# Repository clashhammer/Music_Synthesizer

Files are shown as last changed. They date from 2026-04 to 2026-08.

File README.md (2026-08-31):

# Music_Synthesizer
A project that studies the effect of sound and how waves produce it. Works like a piano and has a screen that outputs like a digital oscilloscope showing the wave that you hear and telling you it's frequency.

I got the idea from a girl I know that wants to be a singer and she said she wanted to buy a synthesizer to get a step closer to composing her own song. That's when I thought "how cool it would be to try and make one, maybe even give it to her if it turns out good.". And yeah, that's basically how I got an idea to build a musical synthesizer.

## Bill of Materials

| Part | Quantity | Price | Link |
|---|---:|---:|---|
| ESP32 DevKit V1 | 1 | €6.89 | [Buy](https://share.temu.com/K3tj6sE6siB) |
| PCM5102 DAC Module | 2 | €2.65 | [Buy](https://a.aliexpress.com/_ExivHVu) |
| XH-A156 Amplifier Board | 1 | €1.29 | [Buy](https://a.aliexpress.com/_EQBbn1Y) |
| 2W 8Ω Speaker | 4 | €2.16 | [Buy](https://a.aliexpress.com/_EGUYYXC) |
| SN74HC595N Shift Register | 1 | €1.93 | [Buy](https://a.aliexpress.com/_EvkP7yO) |
| GMT020-02-8P TFT Display | 1 | — | Any compatible ST7789 TFT display should work |
| Push Button | 26 | — | Any suitable push button set should work |
| 1N4148 Diode | 24 | €3.86 | [Buy](https://share.temu.com/MGWPABEpR8B) |
| 10kΩ Resistor | 4 | €0.87 | [Buy](https://share.temu.com/5ZgNjFWWyZB) |
| 100nF Ceramic Capacitor | 1 | — | Any 100 nF ceramic capacitor should work |

To build a prototype follow the schematic and see where each wire is connected then upload the code to the ESP32 to use it. My own prototype uses just one custom PAM 8403 amplifier board and just one PCM5102 DAC board. I have color coded and connected all parts adjusting to the pinout and code in the schematic for easy understanding.

Also for the code you'll need to download some libraries from the ARDUINO IDE library picker for the code to propperly compile. These are:
- ESP_I2S (should be the second one in the list)
- Adafruit_GFX (again should be second one)
- Adafruit_ST7789 (first one this time)

I also have some custom part signs that I've uploaded as a rar file.

Btw if you haven't used ESP32 before (like me), to connect it to your computer and upload the code you need to install a driver, corelating to what your ESP32 type is. There is a little chip under the big one on the board. To install the correct drivers you need to see what the letters on this chip say. If they say "SILABS CP210x" you need to install the CP210x driver. If it says "CH340" you need to install the CH340 driver on your computer. if it says nothing you need to install the CH340 driver.

Here are the links to both drivers' sites
- CP210x - https://www.silabs.com/software-and-tools/usb-to-uart-bridge-vcp-drivers?tab=overview

- CH340 - https://www.wch-ic.com/downloads/CH341SER_EXE.html

Here are some photos of the finished part of the project like schematic, pcb and 3D display of it and youtube video of how it works.





Youtube video (unlisted): https://youtube.com/shorts/R9iYHdPvPAw

This isn't final and I'll make more updates in the future, thus the not so explanatory explanations.

I added an MIT Licence for free use of my project files.

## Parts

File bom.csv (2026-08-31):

Part | Quantity | Price | Link
ESP32 DevKit V1 | 1 | €6 | 89 | https://share.temu.com/K3tj6sE6siB
PCM5102 DAC Module | 2 | €2 | 65 | https://a.aliexpress.com/_ExivHVu
XH-A156 Amplifier Board | 1 | €1.29 | https://a.aliexpress.com/_EQBbn1Y
2W 8Ω Speaker | 4 | €2.16 | https://a.aliexpress.com/_EGUYYXC
SN74HC595N Shift Register | 1 | €1.93 | https://a.aliexpress.com/_EvkP7yO
GMT020-02-8P TFT Display | 1 |  | can't find a link | any ST7789 TFT display should work.
Push Button | 26 |  | can't find link | any push button set should work
1N4148 Diode | 24 | €3 | 86 | https://share.temu.com/MGWPABEpR8B
10k Ohm Resistor | 4 | €0 | 87 | https://share.temu.com/5ZgNjFWMyZB
100nF Ceramic Capacitor | 1 |  | can't find a direct link | any 100 nF ceramic capacitor should work.

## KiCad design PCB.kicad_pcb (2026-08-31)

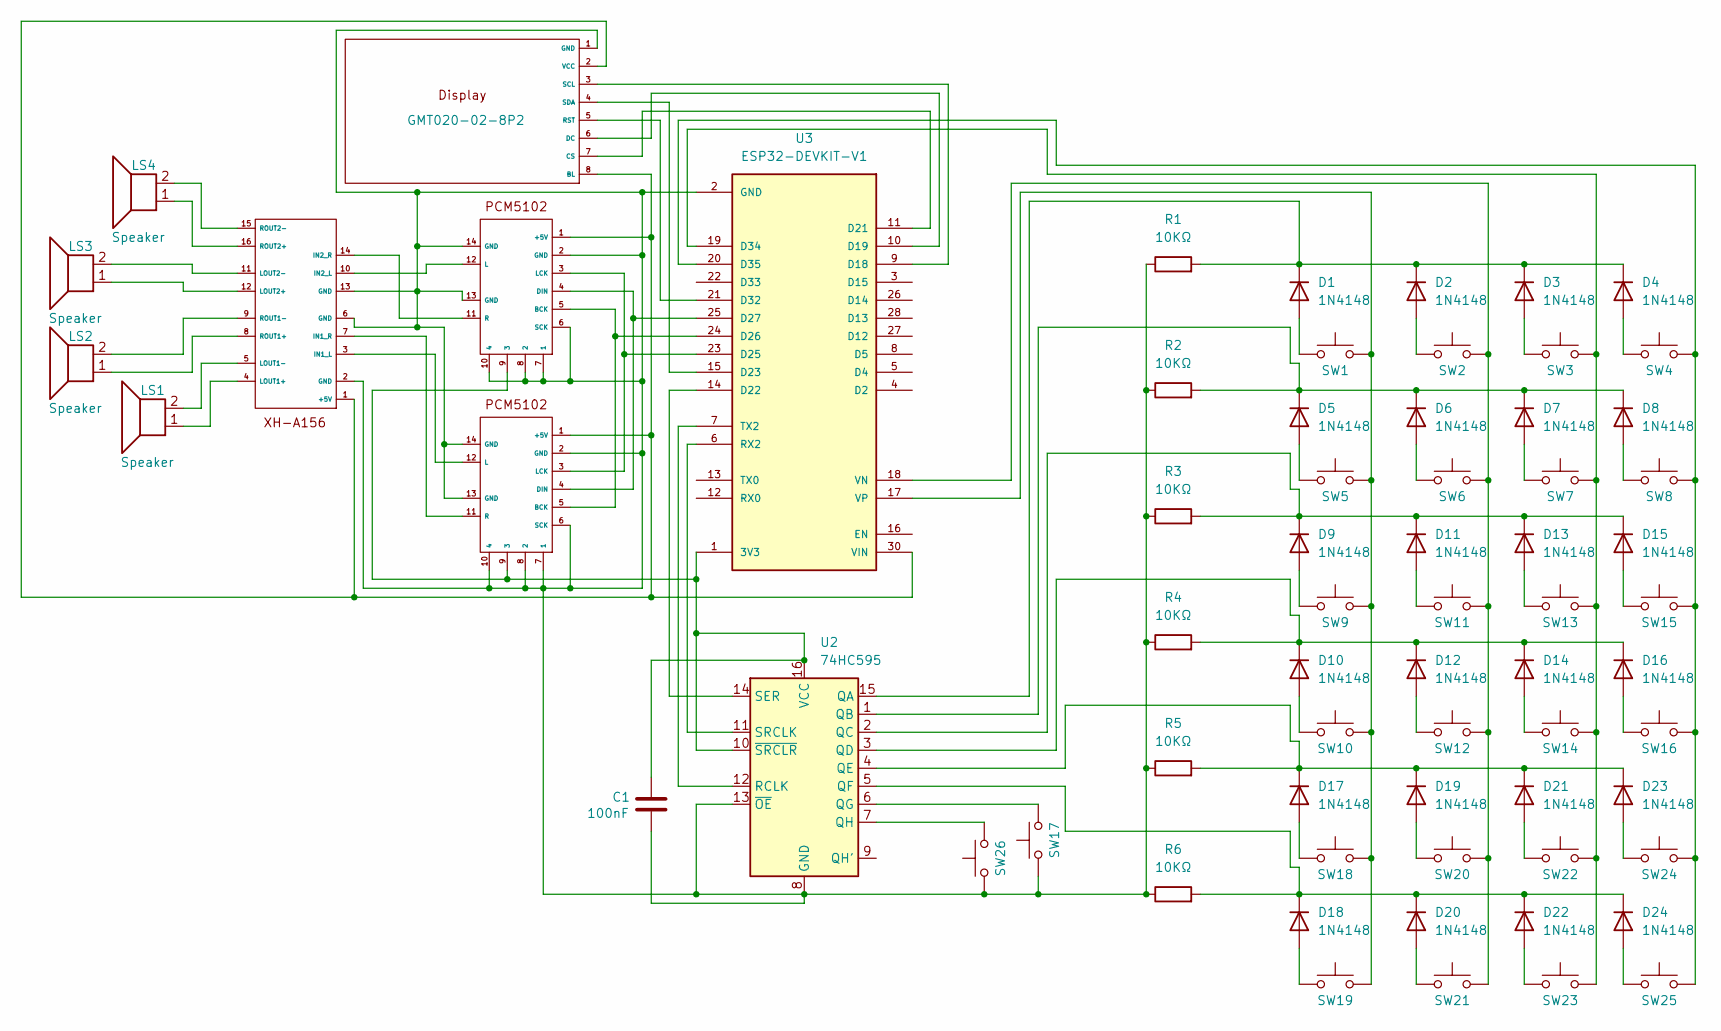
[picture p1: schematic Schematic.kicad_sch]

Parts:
C1: 100nF; C_Disc_D5.0mm_W2.5mm_P5.00mm
D1, D2, D3, D4, D5, D6, D7, D8, D9, D10, D11, D12, D13, D14, D15, D16, D17, D18, D19, D20, D21, D22, D23, D24: 1N4148; D_DO-35_SOD27_P7.62mm_Horizontal
GMT020-02-8P2: GMT020-02-8P
LS1, LS2, LS3, LS4: Speaker; PinHeader_1x02_P2.54mm_Horizontal
PCM1, PCM3: PCM5102
R1, R2, R3, R4, R5, R6: 10KΩ; R_Axial_DIN0207_L6.3mm_D2.5mm_P7.62mm_Horizontal
SW1, SW2, SW3, SW4, SW5, SW6, SW7, SW8, SW9, SW10, SW11, SW12, SW13, SW14, SW15, SW16, SW18, SW19, SW20, SW21, SW22, SW23, SW24, SW25: SW_Push; SW_PUSH-12mm
SW17, SW26: SW_Push; SW_PUSH_6mm
U2: 74HC595; DIP-16_W7.62mm
U3: ESP32-DEVKIT-V1; MODULE_ESP32_DEVKIT_V1; PARTREV N/A
XH-A1: XH-A156 4-way amplifier board

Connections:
GND: C1.2, GMT020-02-8P2.1 (GND), PCM1.2 (GND), PCM1.6 (SCK), PCM1.7 (1), PCM1.8 (2), PCM1.10 (4), PCM1.13 (GND), PCM1.14 (GND), PCM3.2 (GND), PCM3.6 (SCK), PCM3.7 (1), PCM3.8 (2), PCM3.10 (4), PCM3.13 (GND), PCM3.14 (GND), R1.1, R2.1, R3.1, R4.1, R5.1, R6.1, SW17.1, SW26.1, U2.8 (GND), U2.13 (~OE), U3.2 (GND), U3.29 (GND), XH-A1.2 (GND), XH-A1.6 (GND), XH-A1.13 (GND)
unnamed: D1.2 (A), SW1.1
unnamed: D1.1 (K), D2.1 (K), D3.1 (K), D4.1 (K), R1.2, U2.15 (QA)
unnamed: D2.2 (A), SW2.1
unnamed: D3.2 (A), SW3.1
unnamed: D4.2 (A), SW4.1
unnamed: D5.2 (A), SW5.1
unnamed: D5.1 (K), D6.1 (K), D7.1 (K), D8.1 (K), R2.2, U2.1 (QB)
unnamed: D6.2 (A), SW6.1
unnamed: D7.2 (A), SW7.1
unnamed: D8.2 (A), SW8.1
unnamed: D9.2 (A), SW9.1
unnamed: D10.2 (A), SW10.1
unnamed: D10.1 (K), D12.1 (K), D14.1 (K), D16.1 (K), R4.2, U2.3 (QD)
unnamed: D11.2 (A), SW11.1
unnamed: D9.1 (K), D11.1 (K), D13.1 (K), D15.1 (K), R3.2, U2.2 (QC)
unnamed: D12.2 (A), SW12.1
unnamed: D13.2 (A), SW13.1
unnamed: D14.2 (A), SW14.1
unnamed: D15.2 (A), SW15.1
unnamed: D16.2 (A), SW16.1
unnamed: D17.2 (A), SW18.1
unnamed: D17.1 (K), D19.1 (K), D21.1 (K), D23.1 (K), R5.2, U2.4 (QE)
unnamed: D18.2 (A), SW19.1
unnamed: D18.1 (K), D20.1 (K), D22.1 (K), D24.1 (K), R6.2, U2.5 (QF)
unnamed: D19.2 (A), SW20.1
unnamed: D20.2 (A), SW21.1
unnamed: D21.2 (A), SW22.1
unnamed: D22.2 (A), SW23.1
unnamed: D23.2 (A), SW24.1
unnamed: D24.2 (A), SW25.1
unnamed: GMT020-02-8P2.2 (VCC), GMT020-02-8P2.8 (BL), PCM1.1 (+5V), PCM3.1 (+5V), U3.30 (VIN), XH-A1.1 (+5V)
unnamed: GMT020-02-8P2.7 (CS), U3.11 (D21)
unnamed: GMT020-02-8P2.6 (DC), U3.10 (D19)
unnamed: GMT020-02-8P2.5 (RST), U3.21 (D32)
unnamed: GMT020-02-8P2.3 (SCL), U3.9 (D18)
unnamed: GMT020-02-8P2.4 (SDA), U3.15 (D23)
unnamed: C1.1, PCM1.9 (3), PCM3.9 (3), U2.10 (~SRCLR), U2.16 (VCC), U3.1 (3V3)
unnamed: PCM1.5 (BCK), PCM3.5 (BCK), U3.24 (D26)
unnamed: PCM1.4 (DIN), PCM3.4 (DIN), U3.25 (D27)
unnamed: PCM1.12 (L), XH-A1.10 (IN2_L)
unnamed: PCM1.3 (LCK), PCM3.3 (LCK), U3.23 (D25)
unnamed: PCM1.11 (R), XH-A1.14 (IN2_R)
unnamed: PCM3.12 (L), XH-A1.3 (IN1_L)
unnamed: PCM3.11 (R), XH-A1.7 (IN1_R)
unnamed: SW17.2, U2.6 (QG)
unnamed: SW26.2, U2.7 (QH)
unnamed: U2.12 (RCLK), U3.7 (TX2)
unnamed: U2.14 (SER), U3.14 (D22)
unnamed: U2.11 (SRCLK), U3.6 (RX2)
unnamed: SW3.2, SW7.2, SW13.2, SW14.2, SW22.2, SW23.2, U3.19 (D34)
unnamed: SW4.2, SW8.2, SW15.2, SW16.2, SW24.2, SW25.2, U3.20 (D35)
unnamed: SW2.2, SW6.2, SW11.2, SW12.2, SW20.2, SW21.2, U3.18 (VN)
unnamed: SW1.2, SW5.2, SW9.2, SW10.2, SW18.2, SW19.2, U3.17 (VP)
unnamed: LS1.1, XH-A1.4 (LOUT1+)
unnamed: LS1.2, XH-A1.5 (LOUT1-)
unnamed: LS3.1, XH-A1.12 (LOUT2+)
unnamed: LS3.2, XH-A1.11 (LOUT2-)
unnamed: LS2.1, XH-A1.8 (ROUT1+)
unnamed: LS2.2, XH-A1.9 (ROUT1-)
unnamed: LS4.1, XH-A1.16 (ROUT2+)
unnamed: LS4.2, XH-A1.15 (ROUT2-)

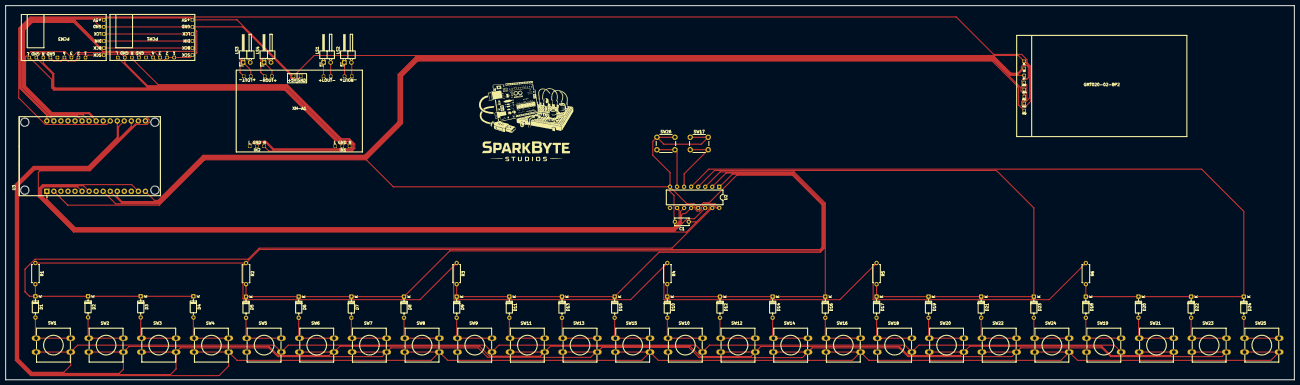
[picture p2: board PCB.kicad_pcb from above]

Board: 2 copper layers, 465.0 x 135.0 mm, 67 parts (0 on the bottom side), 62 nets.

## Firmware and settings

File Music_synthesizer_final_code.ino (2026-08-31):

#include <Arduino.h>
#include <ESP_I2S.h>
#include <SPI.h>
#include <Adafruit_GFX.h>
#include <Adafruit_ST7789.h>

constexpr uint8_t I2S_LCK = 25;
constexpr uint8_t I2S_DIN = 27;
constexpr uint8_t I2S_BCK = 26;

constexpr uint8_t SHIFT_DATA = 22;
constexpr uint8_t SHIFT_CLOCK = 16;
constexpr uint8_t SHIFT_LATCH = 17;

constexpr uint8_t TFT_SCK = 18;
constexpr uint8_t TFT_MOSI = 23;
constexpr uint8_t TFT_CS = 21;
constexpr uint8_t TFT_DC = 19;
constexpr uint8_t TFT_RST = 32;

constexpr uint8_t MATRIX_ROWS = 6;
constexpr uint8_t MATRIX_COLS = 4;
constexpr uint8_t NUM_KEYS = 24;

constexpr uint8_t COL_PINS[MATRIX_COLS] = {
  36,
  39,
  34,
  35
};

constexpr uint8_t WAVE_OUTPUT = 6;
constexpr uint8_t TONE_OUTPUT = 7;

constexpr uint8_t WAVE_COUNT = 5;
constexpr uint8_t TONE_COUNT = 5;

constexpr uint32_t SAMPLE_RATE = 44100;
constexpr uint16_t AUDIO_FRAMES = 128;
constexpr uint16_t SCOPE_BUFFER_SIZE = 4096;

constexpr float TWO_PI_F = 6.28318530718f;
constexpr float MASTER_VOLUME = 0.05f;

const float notes[NUM_KEYS] = {
  261.63f,
  277.18f,
  293.66f,
  311.13f,
  329.63f,
  349.23f,
  369.99f,
  392.00f,
  415.30f,
  440.00f,
  466.16f,
  493.88f,
  523.25f,
  554.37f,
  587.33f,
  622.25f,
  659.25f,
  698.46f,
  739.99f,
  783.99f,
  830.61f,
  880.00f,
  932.33f,
  987.77f
};

const char* noteNames[NUM_KEYS] = {
  "C4",
  "C#4",
  "D4",
  "D#4",
  "E4",
  "F4",
  "F#4",
  "G4",
  "G#4",
  "A4",
  "A#4",
  "B4",
  "C5",
  "C#5",
  "D5",
  "D#5",
  "E5",
  "F5",
  "F#5",
  "G5",
  "G#5",
  "A5",
  "A#5",
  "B5"
};

const char* waveNames[WAVE_COUNT] = {
  "SINE",
  "SQUARE",
  "SAW",
  "TRIANGLE",
  "PULSE"
};

const char* toneNames[TONE_COUNT] = {
  "NORMAL",
  "BASS",
  "TREBLE",
  "MELLOW",
  "BRIGHT"
};

I2SClass I2S;

Adafruit_ST7789 tft(TFT_CS, TFT_DC, TFT_RST);

volatile uint32_t pressedMask = 0;
volatile uint8_t waveType = 0;
volatile uint8_t toneType = 0;

uint32_t debounceMask = 0;
uint32_t previousMask = 0;
uint32_t debounceStart = 0;

bool waveRaw = false;
bool waveStable = false;
uint32_t waveChangeTime = 0;

bool toneRaw = false;
bool toneStable = false;
uint32_t toneChangeTime = 0;

uint32_t lastDisplayUpdate = 0;

float phases[NUM_KEYS] = {};
float gains[NUM_KEYS] = {};

float bassLP = 0.0f;
float trebleLP = 0.0f;
float mellowLP = 0.0f;
float brightLP = 0.0f;

int16_t audioBuffer[AUDIO_FRAMES * 2];

volatile int16_t scopeBuffer[SCOPE_BUFFER_SIZE] = {};
volatile uint16_t scopeWriteIndex = 0;

constexpr int16_t SCREEN_W = 320;
constexpr int16_t SCREEN_H = 240;

constexpr int16_t SCOPE_X = 45;
constexpr int16_t SCOPE_Y = 31;
constexpr int16_t SCOPE_W = 270;
constexpr int16_t SCOPE_H = 155;

void write595(uint8_t value) {
  digitalWrite(SHIFT_LATCH, LOW);
  shiftOut(SHIFT_DATA, SHIFT_CLOCK, MSBFIRST, value);
  digitalWrite(SHIFT_LATCH, HIGH);
}

uint32_t scanMatrix() {
  uint32_t result = 0;

  for (uint8_t row = 0; row < MATRIX_ROWS; row++) {
    write595(1 << row);

    delayMicroseconds(10);

    for (uint8_t column = 0; column < MATRIX_COLS; column++) {
      if (digitalRead(COL_PINS[column]) == HIGH) {
        uint8_t key = row * MATRIX_COLS + column;
        result |= (1UL << key);
      }
    }
  }

  write595(0x00);

  return result;
}

void updateKeyboard() {
  uint32_t rawMask = scanMatrix();
  uint32_t now = millis();

  if (rawMask != debounceMask) {
    debounceMask = rawMask;
    debounceStart = now;
  }

  if (now - debounceStart >= 8) {
    pressedMask = debounceMask;
  }
}

bool readShiftButton(uint8_t output) {
  write595(1 << output);

  delayMicroseconds(10);

  bool pressed =
    digitalRead(COL_PINS[0]) == HIGH;

  write595(0x00);

  return pressed;
}

void updateControlButtons() {
  uint32_t now = millis();

  bool newWaveRaw =
    readShiftButton(WAVE_OUTPUT);

  if (newWaveRaw != waveRaw) {
    waveRaw = newWaveRaw;
    waveChangeTime = now;
  }

  if (
    now - waveChangeTime >= 25 &&
    waveStable != waveRaw
  ) {
    waveStable = waveRaw;

    if (waveStable) {
      waveType++;

      if (waveType >= WAVE_COUNT) {
        waveType = 0;
      }

      Serial.print("WAVE: ");
      Serial.println(waveNames[waveType]);
    }
  }

  bool newToneRaw =
    readShiftButton(TONE_OUTPUT);

  if (newToneRaw != toneRaw) {
    toneRaw = newToneRaw;
    toneChangeTime = now;
  }

  if (
    now - toneChangeTime >= 25 &&
    toneStable != toneRaw
  ) {
    toneStable = toneRaw;

    if (toneStable) {
      toneType++;

      if (toneType >= TONE_COUNT) {
        toneType = 0;
      }

      Serial.print("TONE: ");
      Serial.println(toneNames[toneType]);
    }
  }
}

float generateWave(uint8_t type, float phase) {
  switch (type) {
    case 0:
      return sinf(phase);

    case 1:
      return phase < PI
        ? 1.0f
        : -1.0f;

    case 2:
      return phase / PI - 1.0f;

    case 3:
      if (phase < PI) {
        return -1.0f +
          2.0f * phase / PI;
      }

      return 3.0f -
        2.0f * phase / PI;

    case 4:
      return phase <
        TWO_PI_F * 0.20f
        ? 1.0f
        : -1.0f;
  }

  return 0.0f;
}

float processTone(
  float sample,
  uint8_t type
) {
  switch (type) {
    case 0:
      return sample;

    case 1:
      bassLP +=
        0.035f *
        (sample - bassLP);

      return
        sample * 0.60f +
        bassLP * 0.70f;

    case 2: {
      trebleLP +=
        0.25f *
        (sample - trebleLP);

      float high =
        sample - trebleLP;

      return
        sample * 0.70f +
        high * 0.75f;
    }

    case 3:
      mellowLP +=
        0.15f *
        (sample - mellowLP);

      return mellowLP;

    case 4: {
      brightLP +=
        0.15f *
        (sample - brightLP);

      float high =
        sample - brightLP;

      return
        sample * 0.75f +
        high * 0.50f;
    }
  }

  return sample;
}

void generateAudio() {
  const float attackStep =
    1.0f /
    (0.008f * SAMPLE_RATE);

  const float releaseStep =
    1.0f /
    (0.030f * SAMPLE_RATE);

  uint32_t currentKeys =
    pressedMask;

  uint8_t currentWave =
    waveType;

  uint8_t currentTone =
    toneType;

  uint32_t newlyPressed =
    currentKeys &
    ~previousMask;

  for (
    uint8_t key = 0;
    key < NUM_KEYS;
    key++
  ) {
    if (
      newlyPressed &
      (1UL << key)
    ) {
      phases[key] = 0.0f;
    }
  }

  previousMask =
    currentKeys;

  for (
    uint16_t frame = 0;
    frame < AUDIO_FRAMES;
    frame++
  ) {
    float mix = 0.0f;
    uint8_t voices = 0;

    for (
      uint8_t key = 0;
      key < NUM_KEYS;
      key++
    ) {
      bool pressed =
        currentKeys &
        (1UL << key);

      if (pressed) {
        gains[key] +=
          attackStep;

        if (
          gains[key] >
          1.0f
        ) {
          gains[key] =
            1.0f;
        }
      } else {
        gains[key] -=
          releaseStep;

        if (
          gains[key] <
          0.0f
        ) {
          gains[key] =
            0.0f;
        }
      }

      if (
        gains[key] >
        0.0001f
      ) {
        float wave =
          generateWave(
            currentWave,
            phases[key]
          );

        mix +=
          wave *
          gains[key];

        voices++;

        phases[key] +=
          TWO_PI_F *
          notes[key] /
          SAMPLE_RATE;

        if (
          phases[key] >=
          TWO_PI_F
        ) {
          phases[key] -=
            TWO_PI_F;
        }
      }
    }

    if (voices > 1) {
      mix /= voices;
    }

    mix =
      processTone(
        mix,
        currentTone
      );

    mix =
      constrain(
        mix,
        -1.0f,
        1.0f
      );

    int16_t scopeSample =
      static_cast<int16_t>(
        mix *
        32767.0f
      );

    scopeBuffer[
      scopeWriteIndex
    ] =
      scopeSample;

    scopeWriteIndex++;

    if (
      scopeWriteIndex >=
      SCOPE_BUFFER_SIZE
    ) {
      scopeWriteIndex = 0;
    }

    int16_t sample =
      static_cast<int16_t>(
        mix *
        MASTER_VOLUME *
        32767.0f
      );

    audioBuffer[
      frame * 2
    ] =
      sample;

    audioBuffer[
      frame * 2 + 1
    ] =
      sample;
  }

  I2S.write(
    reinterpret_cast<uint8_t*>(
      audioBuffer
    ),
    sizeof(audioBuffer)
  );
}

void audioTask(
  void* parameter
) {
  while (true) {
    generateAudio();
  }
}

uint8_t countVoices(
  uint32_t mask
) {
  uint8_t voices = 0;

  for (
    uint8_t key = 0;
    key < NUM_KEYS;
    key++
  ) {
    if (
      mask &
      (1UL << key)
    ) {
      voices++;
    }
  }

  return voices;
}

float lowestFrequency(
  uint32_t mask
) {
  for (
    uint8_t key = 0;
    key < NUM_KEYS;
    key++
  ) {
    if (
      mask &
      (1UL << key)
    ) {
      return notes[key];
    }
  }

  return 0.0f;
}

void drawStaticScreen() {
  tft.fillScreen(
    ST77XX_BLACK
  );

  tft.setTextWrap(false);

  tft.drawRect(
    SCOPE_X,
    SCOPE_Y,
    SCOPE_W,
    SCOPE_H,
    ST77XX_WHITE
  );

  tft.setTextColor(
    ST77XX_WHITE
  );

  tft.setTextSize(1);

  tft.setCursor(
    3,
    SCOPE_Y - 3
  );

  tft.print("+1");

  tft.setCursor(
    12,
    SCOPE_Y +
    SCOPE_H / 2 -
    3
  );

  tft.print("0");

  tft.setCursor(
    3,
    SCOPE_Y +
    SCOPE_H -
    6
  );

  tft.print("-1");
}

uint16_t findTriggeredStart(
  uint16_t endIndex,
  uint16_t sampleSpan
) {
  int32_t start =
    static_cast<int32_t>(
      endIndex
    ) -
    sampleSpan -
    200;

  while (start < 0) {
    start +=
      SCOPE_BUFFER_SIZE;
  }

  uint16_t candidate =
    static_cast<uint16_t>(
      start
    );

  for (
    uint16_t i = 1;
    i < 200;
    i++
  ) {
    uint16_t previousIndex =
      (candidate + i - 1) %
      SCOPE_BUFFER_SIZE;

    uint16_t currentIndex =
      (candidate + i) %
      SCOPE_BUFFER_SIZE;

    int16_t previous =
      scopeBuffer[
        previousIndex
      ];

    int16_t current =
      scopeBuffer[
        currentIndex
      ];

    if (
      previous < 0 &&
      current >= 0
    ) {
      return currentIndex;
    }
  }

  return candidate;
}

void drawHeader(
  uint32_t keys,
  uint8_t currentWave,
  uint8_t currentTone
) {
  tft.fillRect(
    0,
    0,
    SCREEN_W,
    29,
    ST77XX_BLACK
  );

  tft.setTextSize(1);

  uint8_t voices =
    countVoices(keys);

  if (voices == 0) {
    tft.setTextColor(
      ST77XX_YELLOW
    );

    tft.setCursor(4, 5);
    tft.print("NO NOTE");
  }

  if (voices == 1) {
    for (
      uint8_t key = 0;
      key < NUM_KEYS;
      key++
    ) {
      if (
        keys &
        (1UL << key)
      ) {
        tft.setTextColor(
          ST77XX_YELLOW
        );

        tft.setCursor(
          4,
          5
        );

        tft.print(
          noteNames[key]
        );

        tft.print(" ");

        tft.print(
          notes[key],
          2
        );

        tft.print("Hz");

        break;
      }
    }
  }

  if (voices > 1) {
    tft.setTextColor(
      ST77XX_YELLOW
    );

    tft.setCursor(4, 5);

    tft.print(voices);
    tft.print(" NOTES");
  }

  tft.setTextColor(
    ST77XX_CYAN
  );

  tft.setCursor(
    245,
    4
  );

  tft.print(
    waveNames[
      currentWave
    ]
  );

  tft.setTextColor(
    ST77XX_MAGENTA
  );

  tft.setCursor(
    245,
    16
  );

  tft.print(
    toneNames[
      currentTone
    ]
  );
}

void drawFrequencyList(
  uint32_t keys
) {
  tft.fillRect(
    0,
    190,
    SCREEN_W,
    50,
    ST77XX_BLACK
  );

  tft.setTextSize(1);

  tft.setTextColor(
    ST77XX_WHITE
  );

  uint8_t active = 0;

  for (
    uint8_t key = 0;
    key < NUM_KEYS;
    key++
  ) {
    if (
      keys &
      (1UL << key)
    ) {
      if (active < 8) {
        uint8_t column =
          active % 4;

        uint8_t row =
          active / 4;

        int16_t x =
          3 +
          column * 79;

        int16_t y =
          194 +
          row * 14;

        tft.setCursor(
          x,
          y
        );

        tft.print(
          notes[key],
          1
        );
      }

      active++;
    }
  }

  if (active == 0) {
    tft.setCursor(
      3,
      194
    );

    tft.print(
      "Frequency: --"
    );
  }

  if (active > 8) {
    tft.setCursor(
      3,
      222
    );

    tft.print("+");
    tft.print(active - 8);
    tft.print(" more");
  }
}

void drawScope(
  uint32_t keys
) {
  tft.fillRect(
    SCOPE_X + 1,
    SCOPE_Y + 1,
    SCOPE_W - 2,
    SCOPE_H - 2,
    ST77XX_BLACK
  );

  uint16_t grid =
    tft.color565(
      40,
      40,
      40
    );

  for (
    uint8_t i = 1;
    i < 4;
    i++
  ) {
    int16_t x =
      SCOPE_X +
      (SCOPE_W * i) /
      4;

    tft.drawFastVLine(
      x,
      SCOPE_Y + 1,
      SCOPE_H - 2,
      grid
    );
  }

  for (
    uint8_t i = 1;
    i < 4;
    i++
  ) {
    int16_t y =
      SCOPE_Y +
      (SCOPE_H * i) /
      4;

    tft.drawFastHLine(
      SCOPE_X + 1,
      y,
      SCOPE_W - 2,
      grid
    );
  }

  int16_t centerY =
    SCOPE_Y +
    SCOPE_H / 2;

  tft.drawFastHLine(
    SCOPE_X + 1,
    centerY,
    SCOPE_W - 2,
    tft.color565(
      90,
      90,
      90
    )
  );

  float frequency =
    lowestFrequency(keys);

  uint16_t sampleSpan =
    700;

  if (
    frequency >
    0.0f
  ) {
    sampleSpan =
      static_cast<uint16_t>(
        SAMPLE_RATE *
        3.0f /
        frequency
      );

    if (
      sampleSpan <
      100
    ) {
      sampleSpan =
        100;
    }

    if (
      sampleSpan >
      1800
    ) {
      sampleSpan =
        1800;
    }
  }

  uint16_t endIndex =
    scopeWriteIndex;

  uint16_t startIndex =
    findTriggeredStart(
      endIndex,
      sampleSpan
    );

  int16_t previousX =
    SCOPE_X + 1;

  int16_t firstSample =
    scopeBuffer[
      startIndex
    ];

  int16_t previousY =
    centerY -
    static_cast<int32_t>(
      firstSample
    ) *
    (SCOPE_H / 2 - 6) /
    32768;

  for (
    int16_t x = 1;
    x < SCOPE_W - 2;
    x++
  ) {
    uint16_t offset =
      static_cast<uint32_t>(
        x
      ) *
      sampleSpan /
      (SCOPE_W - 3);

    uint16_t index =
      (
        startIndex +
        offset
      ) %
      SCOPE_BUFFER_SIZE;

    int16_t value =
      scopeBuffer[
        index
      ];

    int16_t currentX =
      SCOPE_X +
      1 +
      x;

    int16_t currentY =
      centerY -
      static_cast<int32_t>(
        value
      ) *
      (SCOPE_H / 2 - 6) /
      32768;

    tft.drawLine(
      previousX,
      previousY,
      currentX,
      currentY,
      ST77XX_GREEN
    );

    previousX =
      currentX;

    previousY =
      currentY;
  }
}

void drawDisplay() {
  uint32_t now =
    millis();

  if (
    now -
    lastDisplayUpdate <
    50
  ) {
    return;
  }

  lastDisplayUpdate =
    now;

  uint32_t keys =
    pressedMask;

  uint8_t currentWave =
    waveType;

  uint8_t currentTone =
    toneType;

  drawHeader(
    keys,
    currentWave,
    currentTone
  );

  drawScope(keys);

  drawFrequencyList(
    keys
  );
}

void setup() {
  Serial.begin(115200);

  delay(500);

  pinMode(
    SHIFT_DATA,
    OUTPUT
  );

  pinMode(
    SHIFT_CLOCK,
    OUTPUT
  );

  pinMode(
    SHIFT_LATCH,
    OUTPUT
  );

  for (
    uint8_t i = 0;
    i < MATRIX_COLS;
    i++
  ) {
    pinMode(
      COL_PINS[i],
      INPUT
    );
  }

  write595(0x00);

  SPI.begin(
    TFT_SCK,
    -1,
    TFT_MOSI,
    TFT_CS
  );

  tft.init(
    240,
    320
  );

  tft.setRotation(1);

  tft.fillScreen(
    ST77XX_BLACK
  );

  tft.setTextColor(
    ST77XX_WHITE
  );

  tft.setTextSize(2);

  tft.setCursor(
    70,
    100
  );

  tft.print(
    "STARTING..."
  );

  I2S.setPins(
    I2S_BCK,
    I2S_LCK,
    I2S_DIN,
    -1,
    -1
  );

  bool i2sOK =
    I2S.begin(
      I2S_MODE_STD,
      SAMPLE_RATE,
      I2S_DATA_BIT_WIDTH_16BIT,
      I2S_SLOT_MODE_STEREO
    );

  if (!i2sOK) {
    Serial.println(
      "I2S FAILED"
    );

    tft.fillScreen(
      ST77XX_BLACK
    );

    tft.setTextColor(
      ST77XX_RED
    );

    tft.setCursor(
      60,
      100
    );

    tft.print(
      "I2S FAILED"
    );

    while (true) {
      delay(1000);
    }
  }

  drawStaticScreen();

  xTaskCreatePinnedToCore(
    audioTask,
    "Audio",
    4096,
    nullptr,
    3,
    nullptr,
    0
  );

  Serial.println(
    "I2S OK"
  );

  Serial.println(
    "SYNTH READY"
  );

  Serial.println(
    "WAVE: SINE"
  );

  Serial.println(
    "TONE: NORMAL"
  );
}

void loop() {
  updateKeyboard();
  updateControlButtons();
  drawDisplay();

  delay(1);
}

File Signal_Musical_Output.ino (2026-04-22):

#include <Arduino.h>

#define DAC_PIN 25      
#define WAVE_BTN 33   

const int notePins[4] = {15, 18, 19, 21}; 
const float frequencies[4] = {261.63, 293.66, 329.63, 349.23};

// --- SYNTH SETTINGS ---
float masterVolume = 0.1; 
float currentGain = 0.0;    // Current volume (0.0 to 1.0)
float releaseSpeed = 0.005; // How fast it fades out (smaller = longer)
float activeFreq = 0;
float phase = 0;
unsigned long lastMicros = 0;

enum WaveType { SINE, SQUARE, TRIANGLE, SAWTOOTH, PULSE, COUNT };
WaveType currentWave = SINE;

void setup() {
  Serial.begin(115200);
  pinMode(WAVE_BTN, INPUT_PULLUP);
  for (int i = 0; i < 4; i++) pinMode(notePins[i], INPUT_PULLUP);
  dacWrite(DAC_PIN, 0);
  lastMicros = micros();
}

void loop() {
  // 1. Wave Selection
  static bool lastWaveBtnState = HIGH;
  bool waveBtnState = digitalRead(WAVE_BTN);
  if (lastWaveBtnState == HIGH && waveBtnState == LOW) {
    currentWave = (WaveType)((currentWave + 1) % COUNT);
    delay(150);
  }
  lastWaveBtnState = waveBtnState;

  // 2. Scan Buttons
  int pressedIndex = -1;
  for (int i = 0; i < 4; i++) {
    if (digitalRead(notePins[i]) == LOW) {
      pressedIndex = i;
      break;
    }
  }

  // 3. Envelope Logic (The "Fade")
  if (pressedIndex != -1) {
    activeFreq = frequencies[pressedIndex];
    currentGain = 1.0; // Instant "Attack"
  } else {
    // Release: Slowly drop the gain to 0
    if (currentGain > 0) {
      currentGain -= releaseSpeed; 
      if (currentGain < 0) currentGain = 0;
    }
  }

  // 4. Audio Generation
  unsigned long currentMicros = micros();
  float delta = (float)(currentMicros - lastMicros);
  lastMicros = currentMicros;

  if (currentGain > 0) {
    float phaseInc = (2.0 * PI * activeFreq) / 1000000.0;
    phase += phaseInc * delta;
    if (phase >= 2.0 * PI) phase -= 2.0 * PI;

    float rawVal = 0;
    switch (currentWave) {
      case SINE:     rawVal = sin(phase); break;
      case SQUARE:   rawVal = (phase < PI) ? 0.5 : -0.5; break;
      case TRIANGLE: rawVal = (phase < PI) ? (2.0 * (phase / PI) - 1.0) : (1.0 - 2.0 * ((phase - PI) / PI)); break;
      case SAWTOOTH: rawVal = ((phase / PI) - 1.0) * 0.7; break;
      case PULSE:    rawVal = (phase < (PI * 0.3)) ? 0.5 : -0.5; break; // Thin 15% pulse
    }
    
    // Apply the Envelope (currentGain)
    int dacOutput = 127 + (int)(rawVal * 127.0 * masterVolume * currentGain);
    dacWrite(DAC_PIN, dacOutput);
  } else {
    dacWrite(DAC_PIN, 127); // Stay at center when silent to avoid DC "thump"
    phase = 0;
  }
}

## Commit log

2026-08-31 Parts list
    Added bill of materials for project components.
    [bom.csv]
2026-08-31 README
    Extended description of my project and instructions on how to make yourself a prototype to test it.
2026-08-31 BOM
    BOM
    [bom.csv]
2026-08-31 README
    Removed duplicate 'Bill of Materials' section from README.
2026-08-31 README
    Added information about custom part signs and driver installation for ESP32. Included a note about future updates and added an MIT License.
2026-09-01 Gerber files and custom parts schematic signs and pcb's.
